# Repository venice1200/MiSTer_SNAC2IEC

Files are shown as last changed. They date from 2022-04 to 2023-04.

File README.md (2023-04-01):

# MiSTer_SNAC2IEC
Inspired from the [SNAC Accessory Converter](https://github.com/blue212/SNAC) and the IEC Support of the C64 Core  
I created together with dtimber this little Adapter PCB for the MiSTer FPGA.  
  
The Adapter converts the MiSTer FPGA User Port (Serial IO) into a Commodore IEC/CBM (Serial) Bus Port.    
Use the Adapter to connect a real Commodore Floppy 1541 or compatible devices (SD2IEC/PI1541) to your MiSTer.  
  
I know there are better and faster ways to load a game into a MiSTer's Core, but this is fun 🚀.  
  
### Compatible & Tested Cores  
C64, C128, Commodore Plus/4  
### Tested Hardware  
[SD2IEC](https://www.c64-wiki.com/wiki/SD2IEC), [PI1541](https://cbm-pi1541.firebaseapp.com/), CBM 1541, CBM1541-II, CBM1571, CBM1581 and Printer MPS-803.
  
Cores and some Hardware Devices are also tested with **JiffyDOS** 🚀.  
  
Double check the User Video below.   
  
### Let's go and have fun...
I used "breakout Parts" for the used Voltage-Levelshifter and the Voltage-Regulator as I had them in stock.  
There is also a Full-SMD-Version available, created by dtimber who created the Case as well.  
  
## PCB's
### First Versions  
### Breakout v1.1/SMD v1.0
The first Picture shows the "Breakout Version", the second the "Full-SMD Version".  
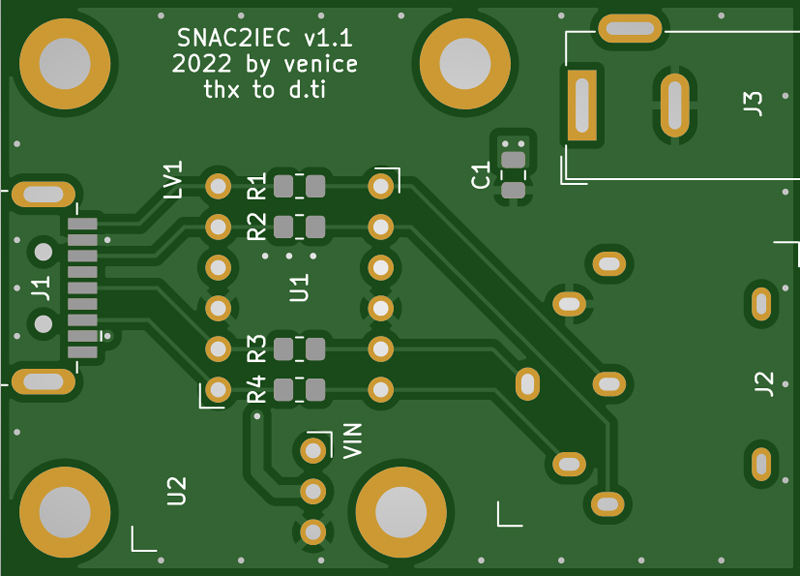
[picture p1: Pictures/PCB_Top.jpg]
 
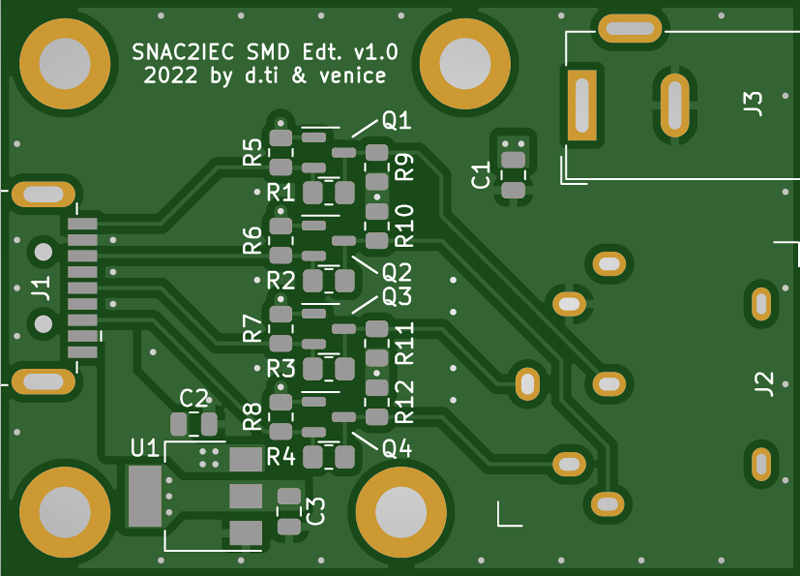
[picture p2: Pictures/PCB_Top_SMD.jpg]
  
  
### Updated Version(s)  
### Breakout v1.2/SMD 1.1  
Changes:
  * Added support for the SRQ Signal which is needed by the C128 Core for **Fast Serial Mode**.  
    The Breakout Version v1.2 need a second Leveshifter **on Top** of the first one to support the SRQ Signal.  
    Solder two small cables from the Pins LV5 and HV5 to one channel of the second Levelshifter.  
  * Removed 5V support (R1-R4) which needs a Standard SNAC Adapter connected before SNAC2IEC.  
  
The first Picture shows the "Breakout Version", the second the "Full-SMD Version".  
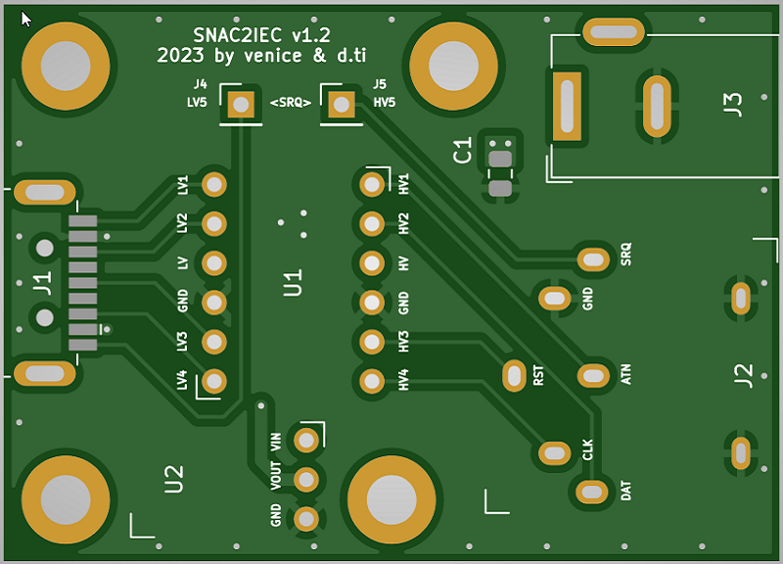
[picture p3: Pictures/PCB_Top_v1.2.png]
 
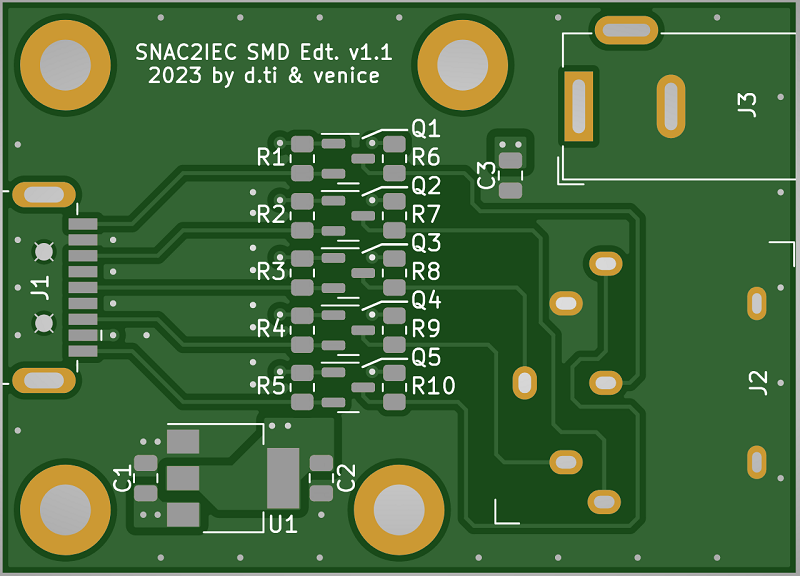
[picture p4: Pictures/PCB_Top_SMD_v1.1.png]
  
  
## More Pictures
The Case was designed to look like the C64 Power Supply  
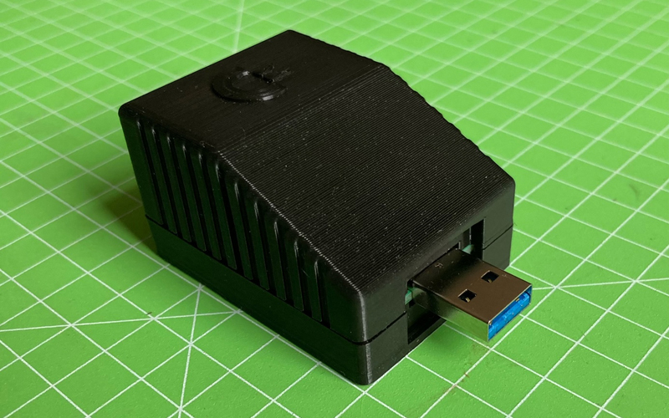
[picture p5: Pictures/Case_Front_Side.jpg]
 
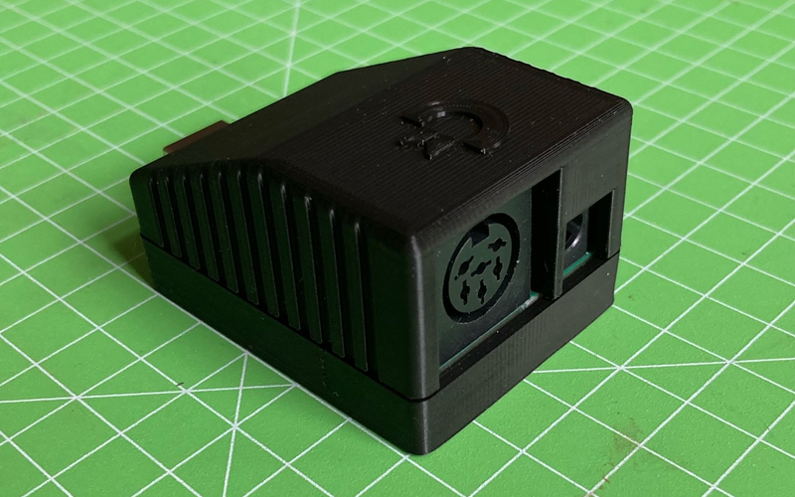
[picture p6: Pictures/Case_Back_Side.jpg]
  
  
Connector View  
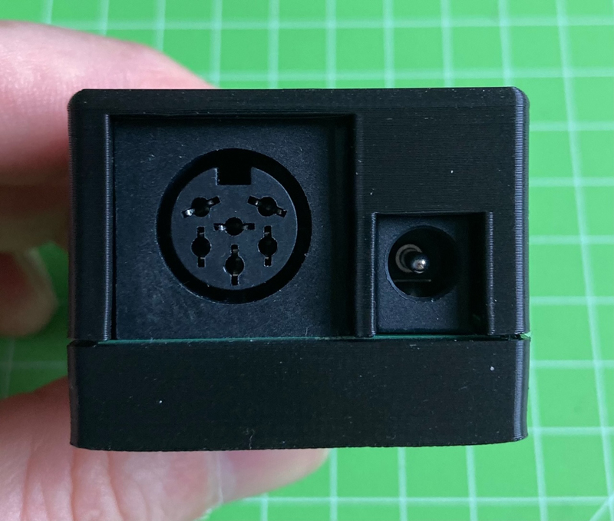
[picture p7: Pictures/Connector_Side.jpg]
  
Left Connector = IEC/CBM Bus, right Connector = 5V Power from SNAC Port  
                                                     
Soldered PCB Version **with** Level Shifter.  
Use it with the Standard IO Board with SNAC Port and **3.3V** Signal Level.  
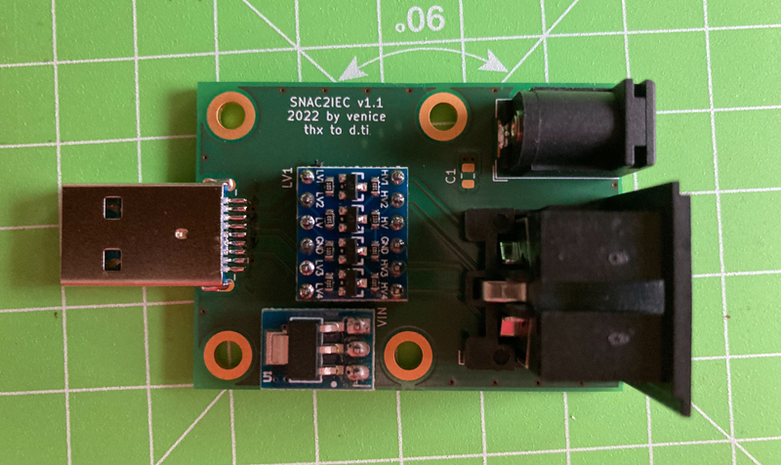
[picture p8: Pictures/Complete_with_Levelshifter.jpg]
  
You need all parts except the "optional's".
  
Soldered PCB Version **without** Level Shifter.  
Only usable with the "first" PCB Versions.  
Use it with SNAC Port's with integrated Level Shifter or with blue212's external SNAC Adapter and **5V** Signal Level.  
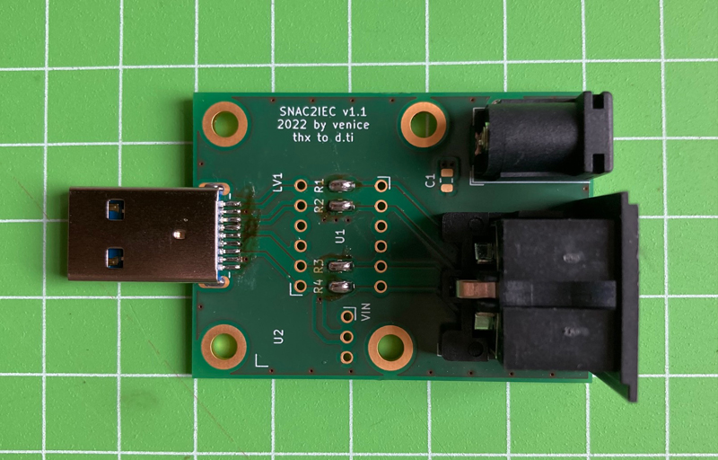
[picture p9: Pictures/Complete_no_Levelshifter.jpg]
  
Just add some 0R 0805 Resistors or a blob of solder to R1,R2,R3 and R4.  

A look inside...  
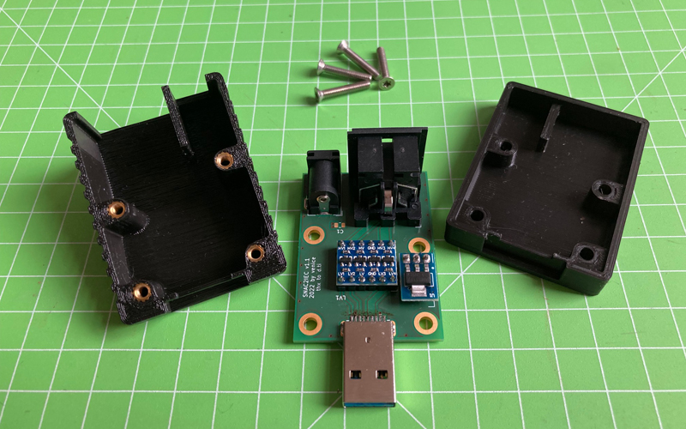
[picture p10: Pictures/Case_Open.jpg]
  
  
All Parts for the Breakout-Version  
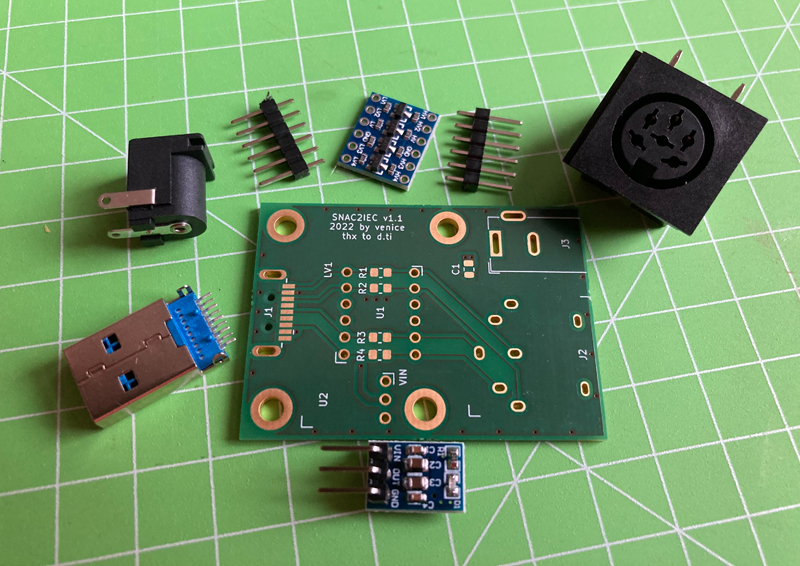
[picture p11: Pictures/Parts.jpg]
  
  
### BOM Breakout Version  
|Part|Type|
|:---|:---|
|R1-R4|0 ohm 0805 resistors (optional, see schematics)|
|C1|4,7uF 0805 capacitor (optional, see schematics)|
|J1|USB3 type A connector|
|J2|6 pin DIN connector (MAS60)|
|J3|DC barrel connector (optional, 5.5/2.1 mm should be fine for most PSUs)|  
|U1|4-Channel Voltage-Levelshifter (5V/3.3V), add a second ***stacked*** Levelshifter for SRQ|
|U2|5V to 3.3V Voltage Regulator|
  
### BOM Full-SMD-Version v1.0 
|Part|Type|
|:---|:---|
|R1-R4|0 ohm 0805 resistors (optional, see schematics)|
|R5-R12|10k 0805 resistors|
|C1-C3|22nf 0805 capacitors|
|Q1-Q4|N-Channel SOT23 MOSFET transistors (BSS138 or similar)|
|U1|3.3v LM1117 SOT223 regulator|
|J1|USB3 type A connector|
|J2|6 pin DIN connector (MAS60)|
|J3|DC barrel connector (optional, 5.5/2.1 mm should be fine for most PSUs)|  
  
### BOM Full-SMD-Version v1.1 
|Part|Type|
|:---|:---|
|R1-R10|10k 0805 resistors|
|C1-C3|22nf 0805 capacitors|
|Q1-Q5|N-Channel SOT23 MOSFET transistors (BSS138 or similar)|
|U1|3.3v LM1117 SOT223 regulator|
|J1|USB3 type A connector|
|J2|6 pin DIN connector (MAS60)|
|J3|DC barrel connector (optional, 5.5/2.1 mm should be fine for most PSUs)|  
  
### Screws and Brass Nuts  
|Part|Type|
|:---|:---|
|Brass Nuts|M3, outer size 4,6mm, lenght 6mm|
|Screws|M3, Counter Sunk, length 17mm|

### Many Thanks to:
*  [dtimber](https://github.com/dtimber) was helping me with KiCad and he is the Creator of the Case and the **SMD-Version**.
  
### Links:  
*  https://github.com/MiSTer-devel/Main_MiSTer/wiki  
*  https://github.com/MiSTer-devel/Main_MiSTer/wiki/User-Port-(Serial-IO)  
*  https://github.com/MiSTer-devel/C64_MiSTer
*  https://github.com/blue212/SNAC
*  https://misterfpga.org/
*  https://misterfpga.org/viewtopic.php?t=4469
  
### User-Videos:  
* https://youtu.be/zR52L662JqI
* https://www.youtube.com/watch?v=zR52L662JqI
* https://www.youtube.com/watch?v=jKdF6Q4ZU_g
* https://www.youtube.com/watch?v=Q-g8Mt_xXnU
* https://www.youtube.com/watch?v=LXGE7Ap88mE
    


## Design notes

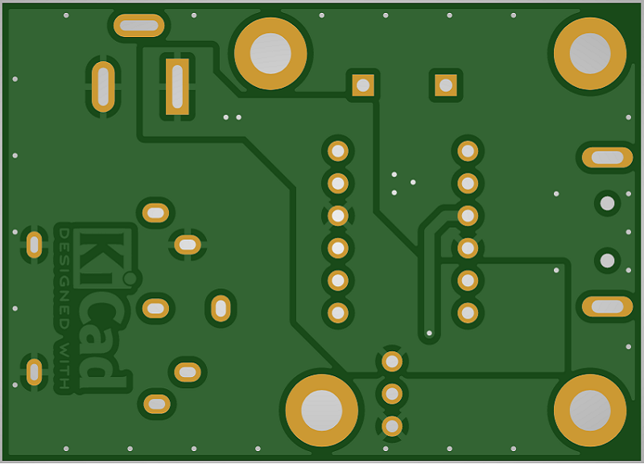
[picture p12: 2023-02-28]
Pictures/PCB_Bottom_v1.2.png

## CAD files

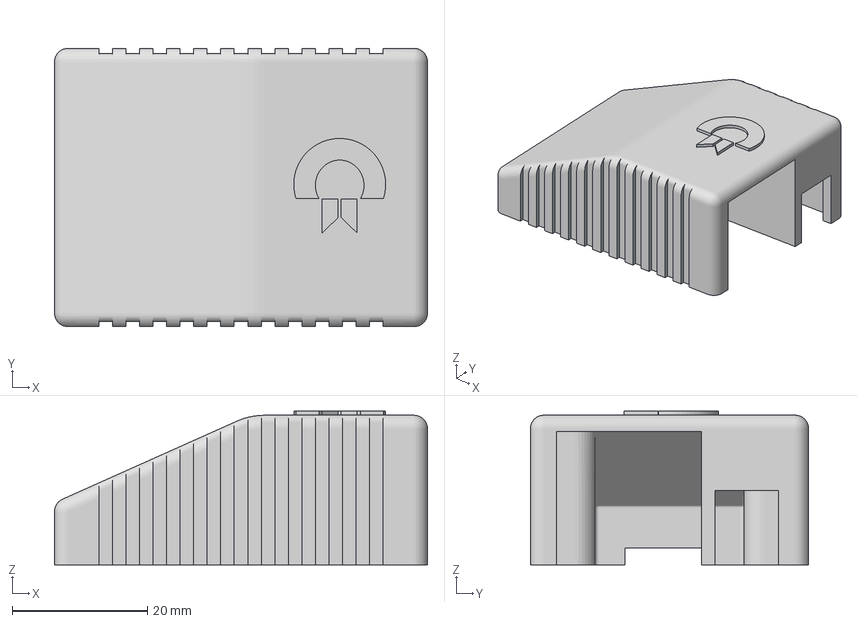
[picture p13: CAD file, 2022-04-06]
3D/Top.3mf
55.2 x 41.2 x 22.8 mm

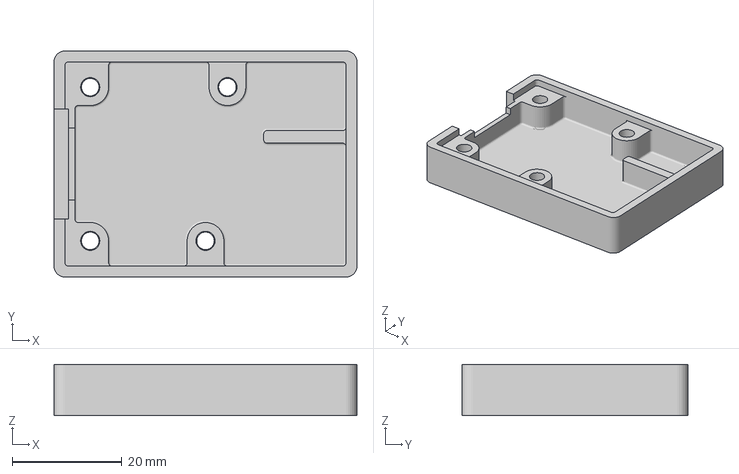
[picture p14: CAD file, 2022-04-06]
3D/Bottom.3mf
55.2 x 41.2 x 9.35 mm

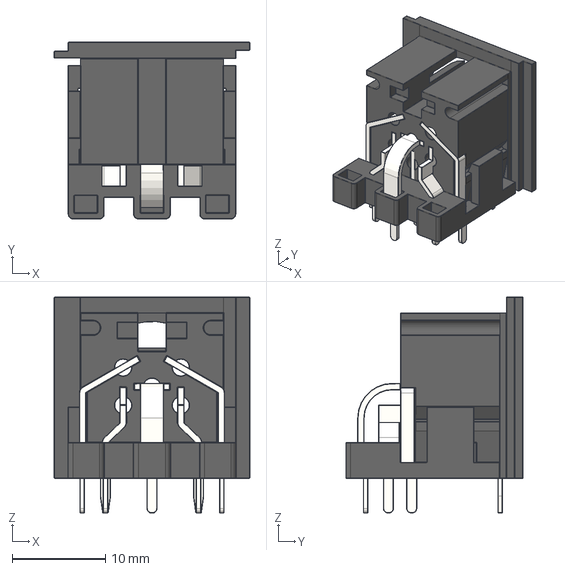
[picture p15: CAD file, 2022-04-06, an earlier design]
KiCad/SD2IEC_SMD_Version/Footprints_und_Symbole/3D/DIN-6-Connector.step
21.0 x 19.0 x 23.2 mm

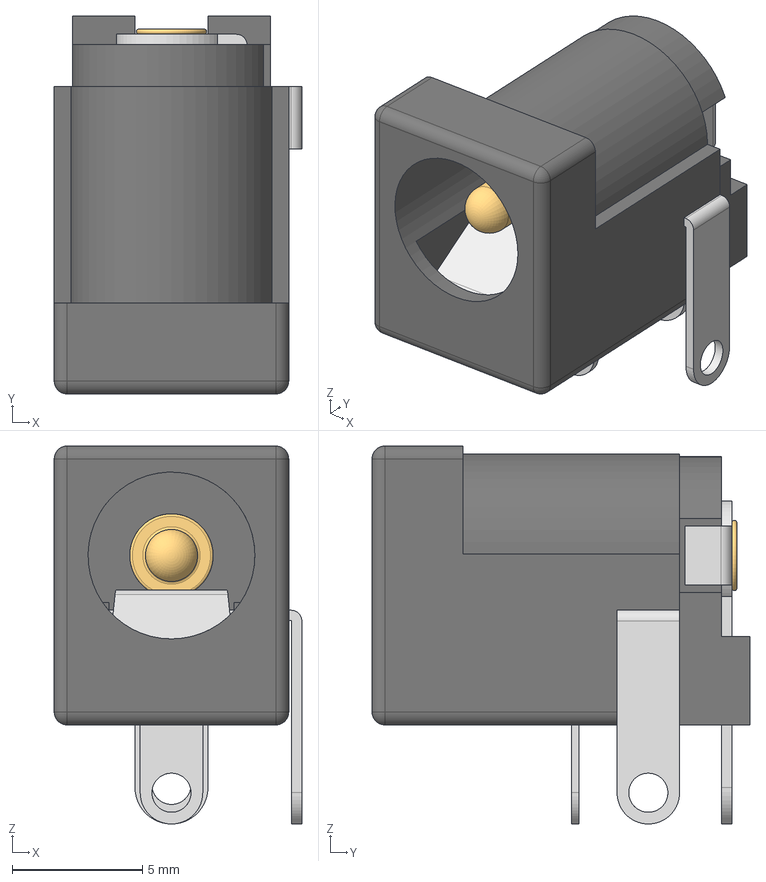
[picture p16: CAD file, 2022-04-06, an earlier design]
KiCad/SD2IEC_SMD_Version/Footprints_und_Symbole/3D/694106301002 (rev1).stp
9.50 x 14.5 x 14.5 mm
6941xx301002
694106301002_PinContact
6941xx301002_Back
6941xx301002_PinContact2
6941xx301002_PinLame
6941xx301002_PinBis

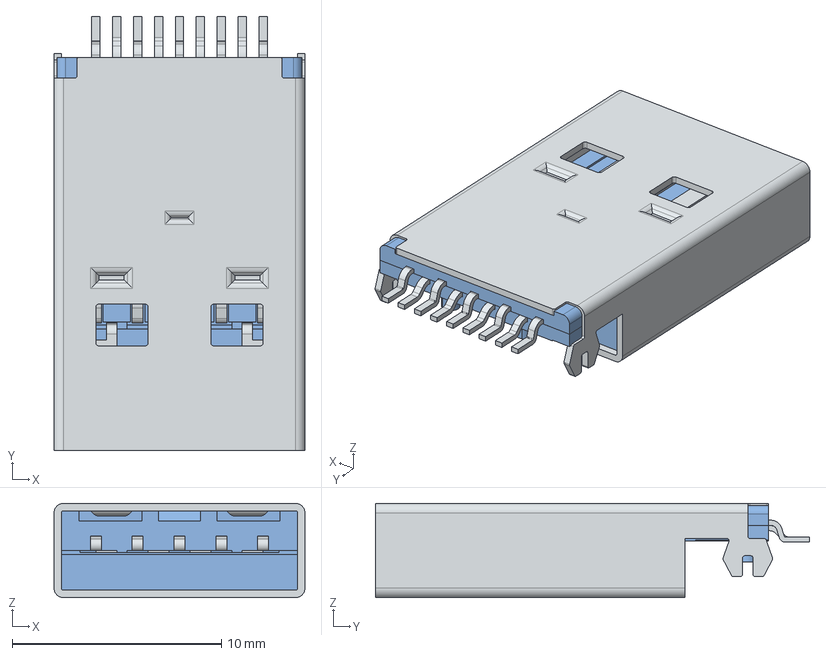
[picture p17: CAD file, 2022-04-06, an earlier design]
KiCad/SD2IEC_SMD_Version/Footprints_und_Symbole/3D/692112030100 (rev1).stp
12.0 x 20.8 x 4.50 mm
692112030100_Housing
692112030100_Shielding
692112030100_Pin2
692112030100_Pin3 x 2
692112030100_Pin1 x 5
692112030100_Housing2
692112030100_Pin5

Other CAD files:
KiCad/SD2IEC_SMD_Version/Footprints_und_Symbole/3D/DIN 45322 Circular Connector.stp
3D/Bottom.stl
3D/SNAC2IEC_Case v8.f3d
3D/Top.stl

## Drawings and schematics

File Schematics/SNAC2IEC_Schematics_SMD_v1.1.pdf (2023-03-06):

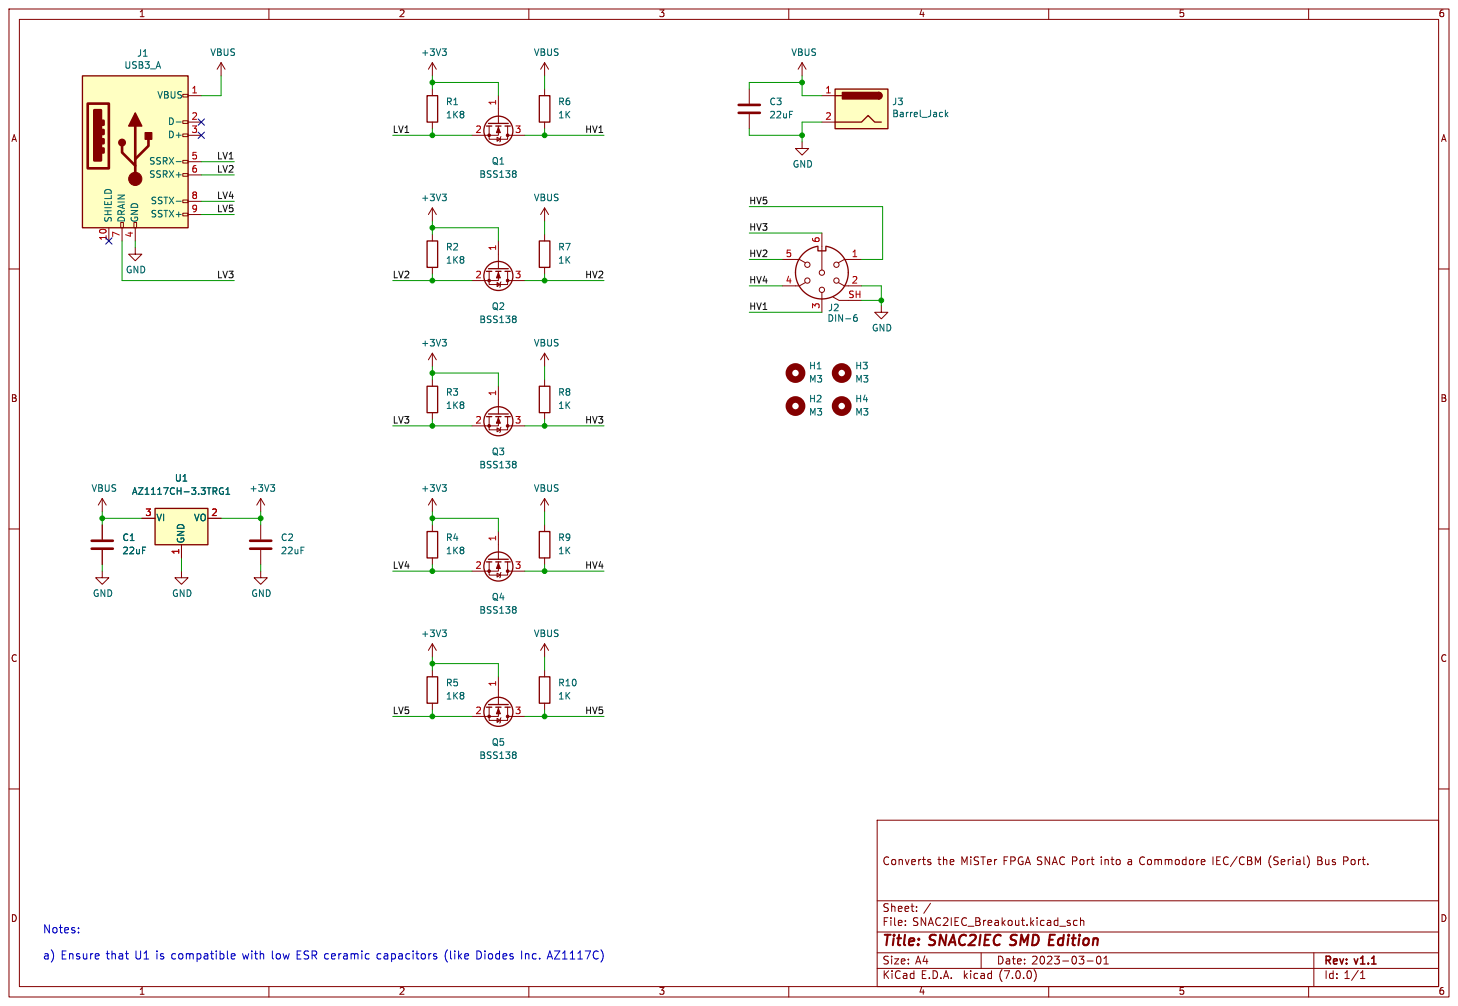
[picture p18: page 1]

Id: 1/1 Title: SNAC2IEC SMD Edition

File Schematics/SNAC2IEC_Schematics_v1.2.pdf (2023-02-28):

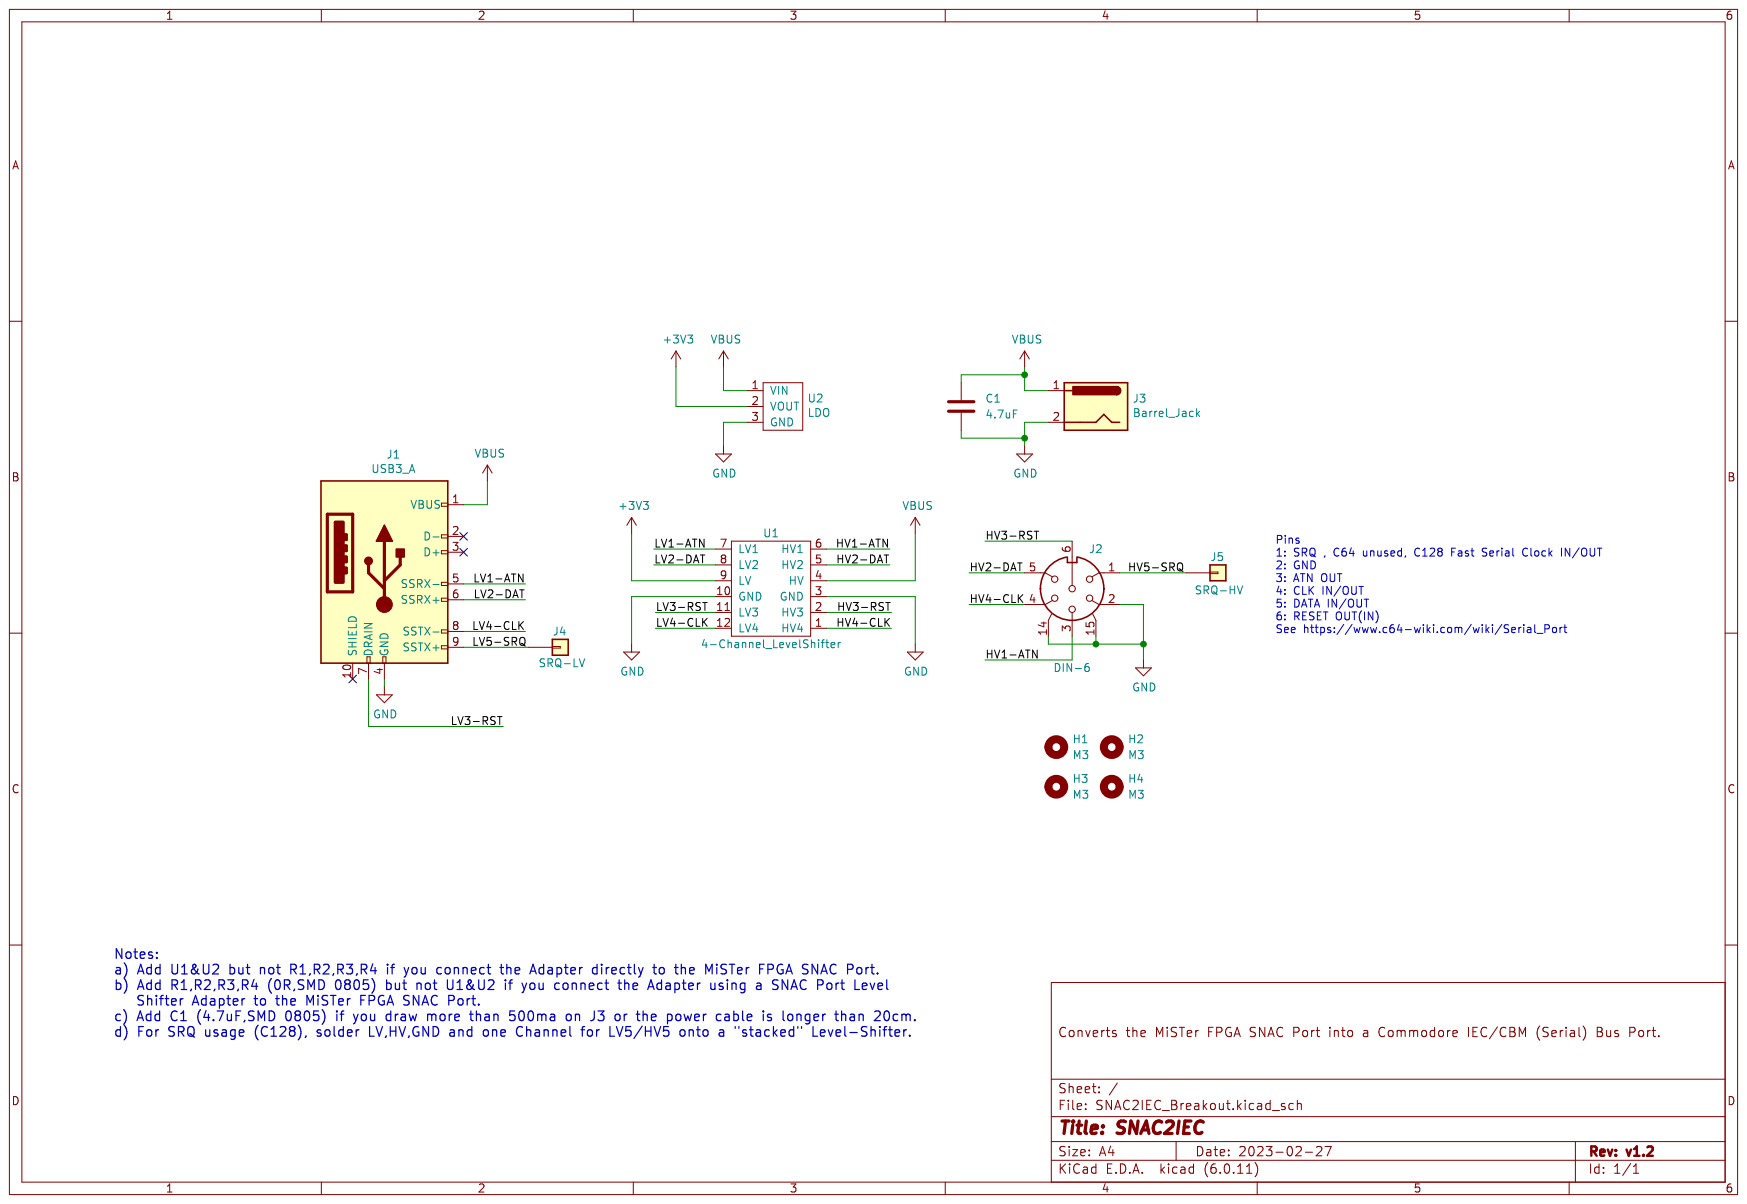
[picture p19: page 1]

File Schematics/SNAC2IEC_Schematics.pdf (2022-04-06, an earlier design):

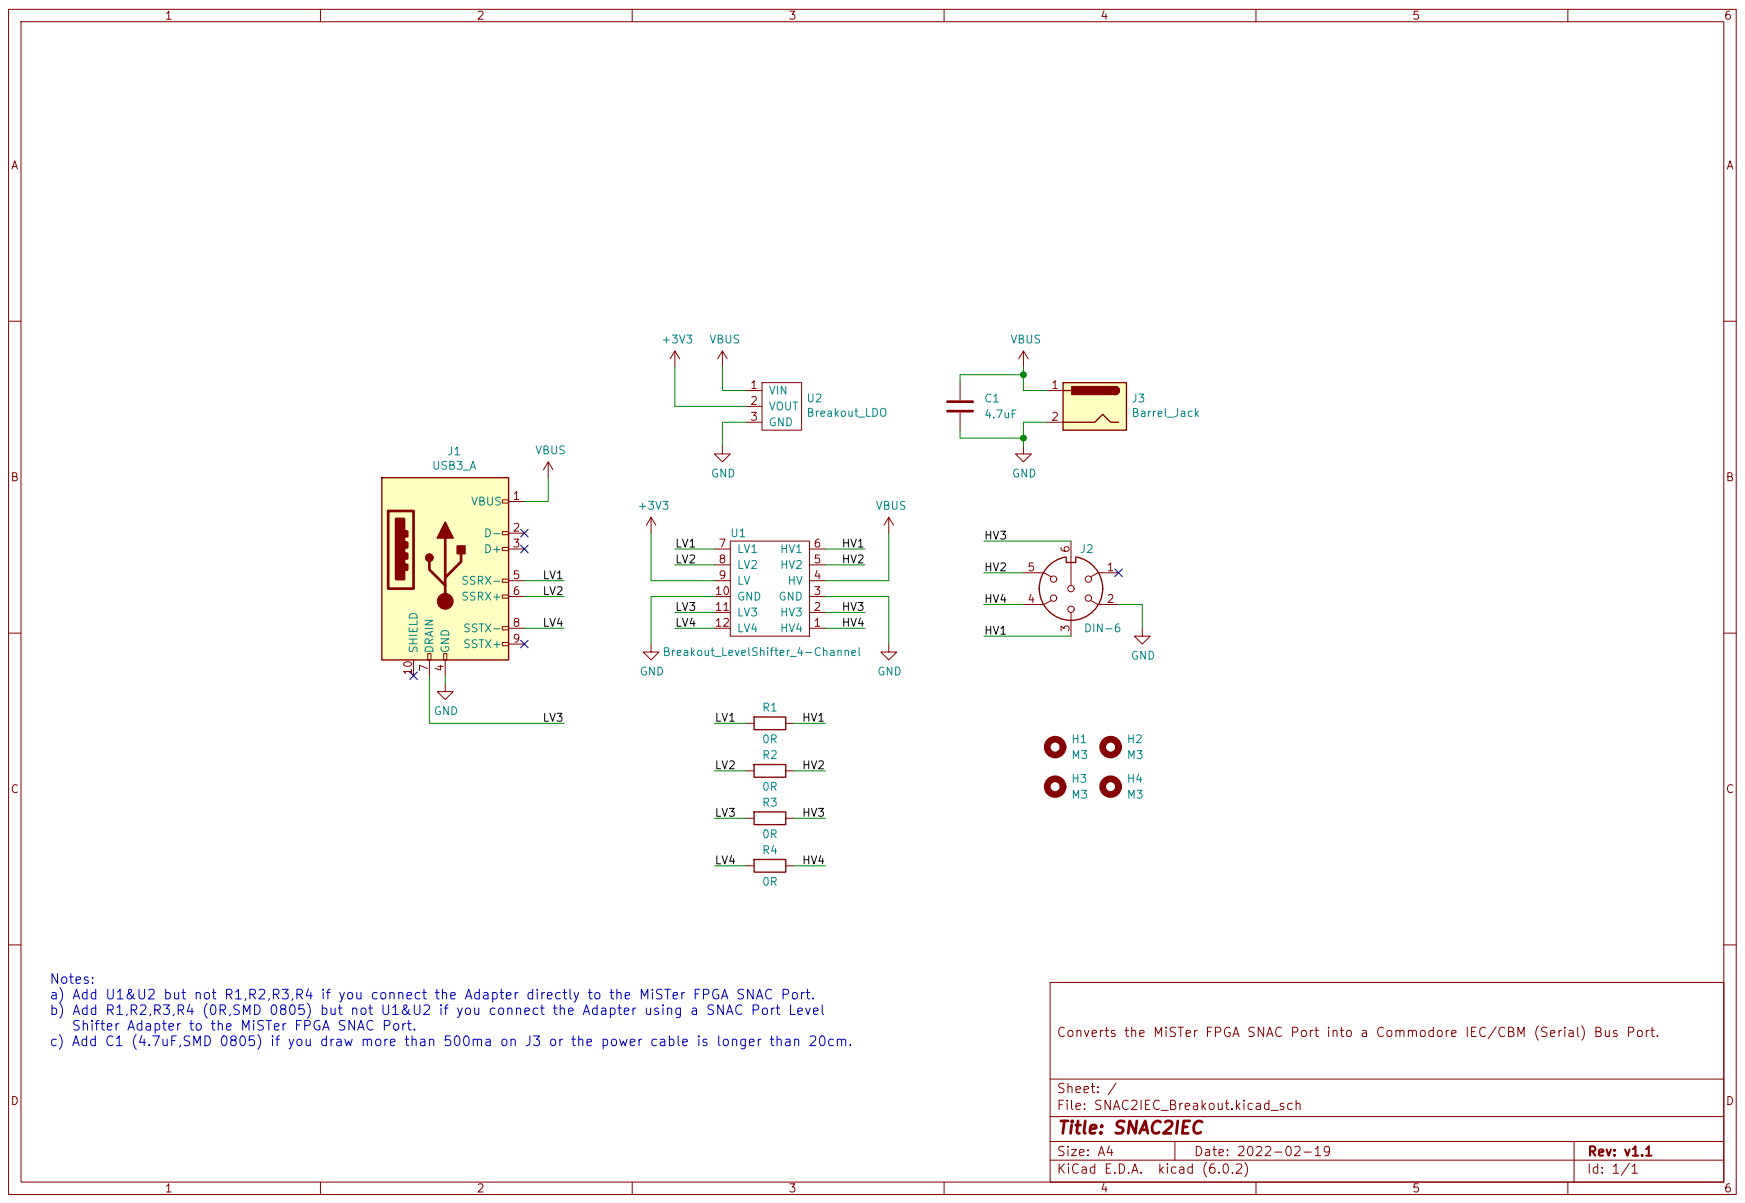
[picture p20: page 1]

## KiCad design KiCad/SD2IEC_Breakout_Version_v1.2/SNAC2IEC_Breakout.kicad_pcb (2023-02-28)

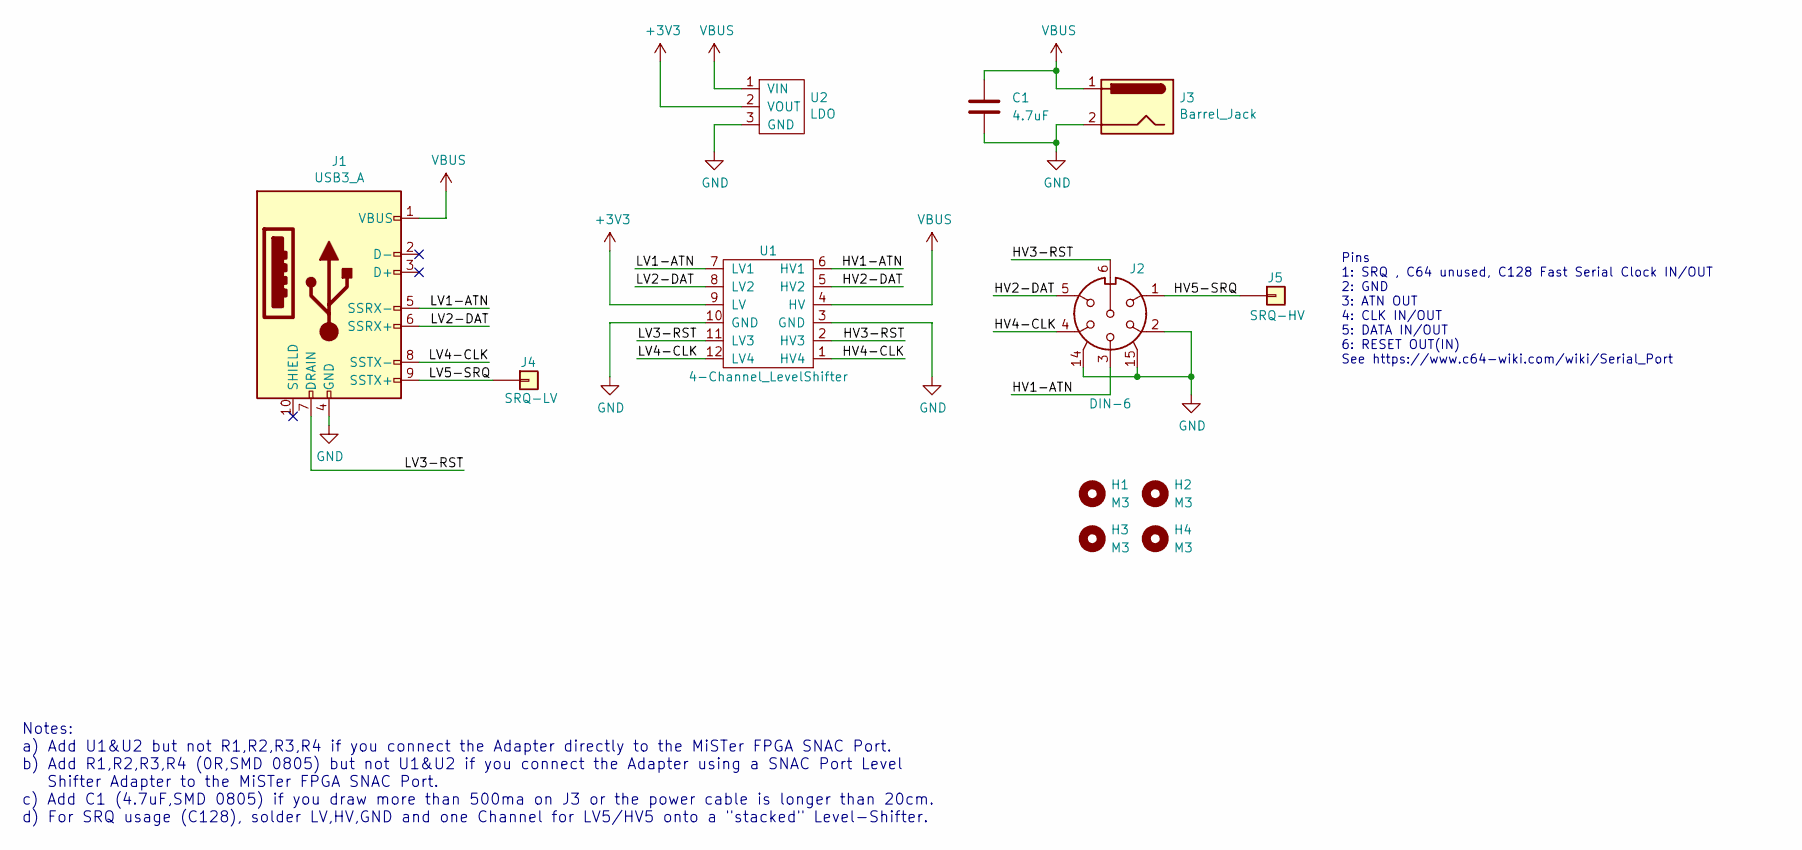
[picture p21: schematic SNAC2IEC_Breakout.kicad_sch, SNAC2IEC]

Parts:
C1: 4.7uF; C_0805_2012Metric
H1, H2, H3, H4: M3; MountingHole_3.2mm_M3_ISO7380_Pad
J1: USB3_A; USB3_A_Plug_Wuerth_692112030100_Horizontal
J2: DIN-6; DIN_6Pin_Print_Connector_IEC_Layout
J3: Barrel_Jack; BarrelJack_Wuerth_6941xx301002
J4: SRQ-LV; PinHeader_1x01_P2.54mm_Vertical
J5: SRQ-HV; PinHeader_1x01_P2.54mm_Vertical
U1: 4-Channel_LevelShifter; Breakout_LevelShiffer_4Channel
U2: LDO; Breakout_LDO_AMS1117_3.3V

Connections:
+3V3: U1.9 (LV), U2.2 (VOUT)
/HV1-ATN: J2.3, U1.6 (HV1)
/HV2-DAT: J2.5, U1.5 (HV2)
/HV3-RST: J2.6, U1.2 (HV3)
/HV4-CLK: J2.4, U1.1 (HV4)
/HV5-SRQ: J2.1, J5.1
/LV1-ATN: J1.5 (SSRX-), U1.7 (LV1)
/LV2-DAT: J1.6 (SSRX+), U1.8 (LV2)
/LV3-RST: J1.7 (DRAIN), U1.11 (LV3)
/LV4-CLK: J1.8 (SSTX-), U1.12 (LV4)
/LV5-SRQ: J1.9 (SSTX+), J4.1
GND: C1.2, J1.4 (GND), J2.2, J2.14, J2.15, J3.2, U1.3 (GND), U1.10 (GND), U2.3 (GND)
VBUS: C1.1, J1.1 (VBUS), J3.1, U1.4 (HV), U2.1 (VIN)

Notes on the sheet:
Notes: a) Add U1&U2 but not R1,R2,R3,R4 if you connect the Adapter directly to the MiSTer FPGA SNAC Port. b) Add R1,R2,R3,R4 (0R,SMD 0805) but not U1&U2 if you connect the Adapter using a SNAC Port Level Shifter Adapter to the MiSTer FPGA SNAC Port. c) Add C1 (4.7uF,SMD 0805) if you draw more than 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
Pins 1: SRQ , C64 unused, C128 Fast Serial Clock IN/OUT 2: GND 3: ATN OUT 4: CLK IN/OUT 5: DATA IN/OUT 6: RESET OUT(IN) See https://www.c64-wiki.com/wiki/Serial_Port

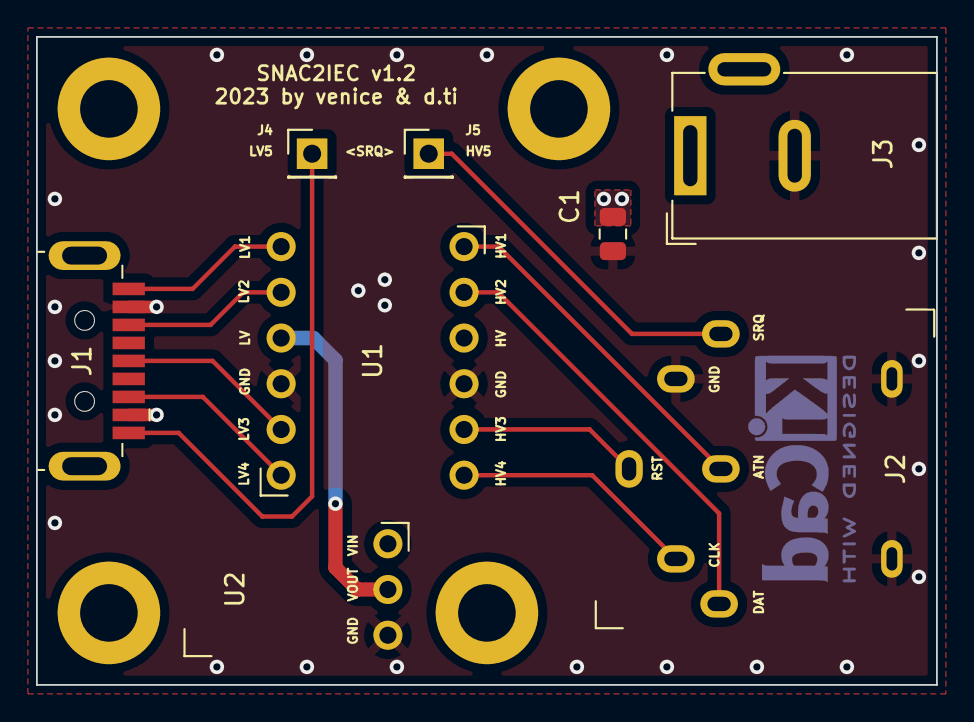
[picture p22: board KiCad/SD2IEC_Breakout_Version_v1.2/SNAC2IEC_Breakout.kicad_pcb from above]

Board: 2 copper layers, 50.0 x 36.0 mm, 12 parts (0 on the bottom side), 13 nets.

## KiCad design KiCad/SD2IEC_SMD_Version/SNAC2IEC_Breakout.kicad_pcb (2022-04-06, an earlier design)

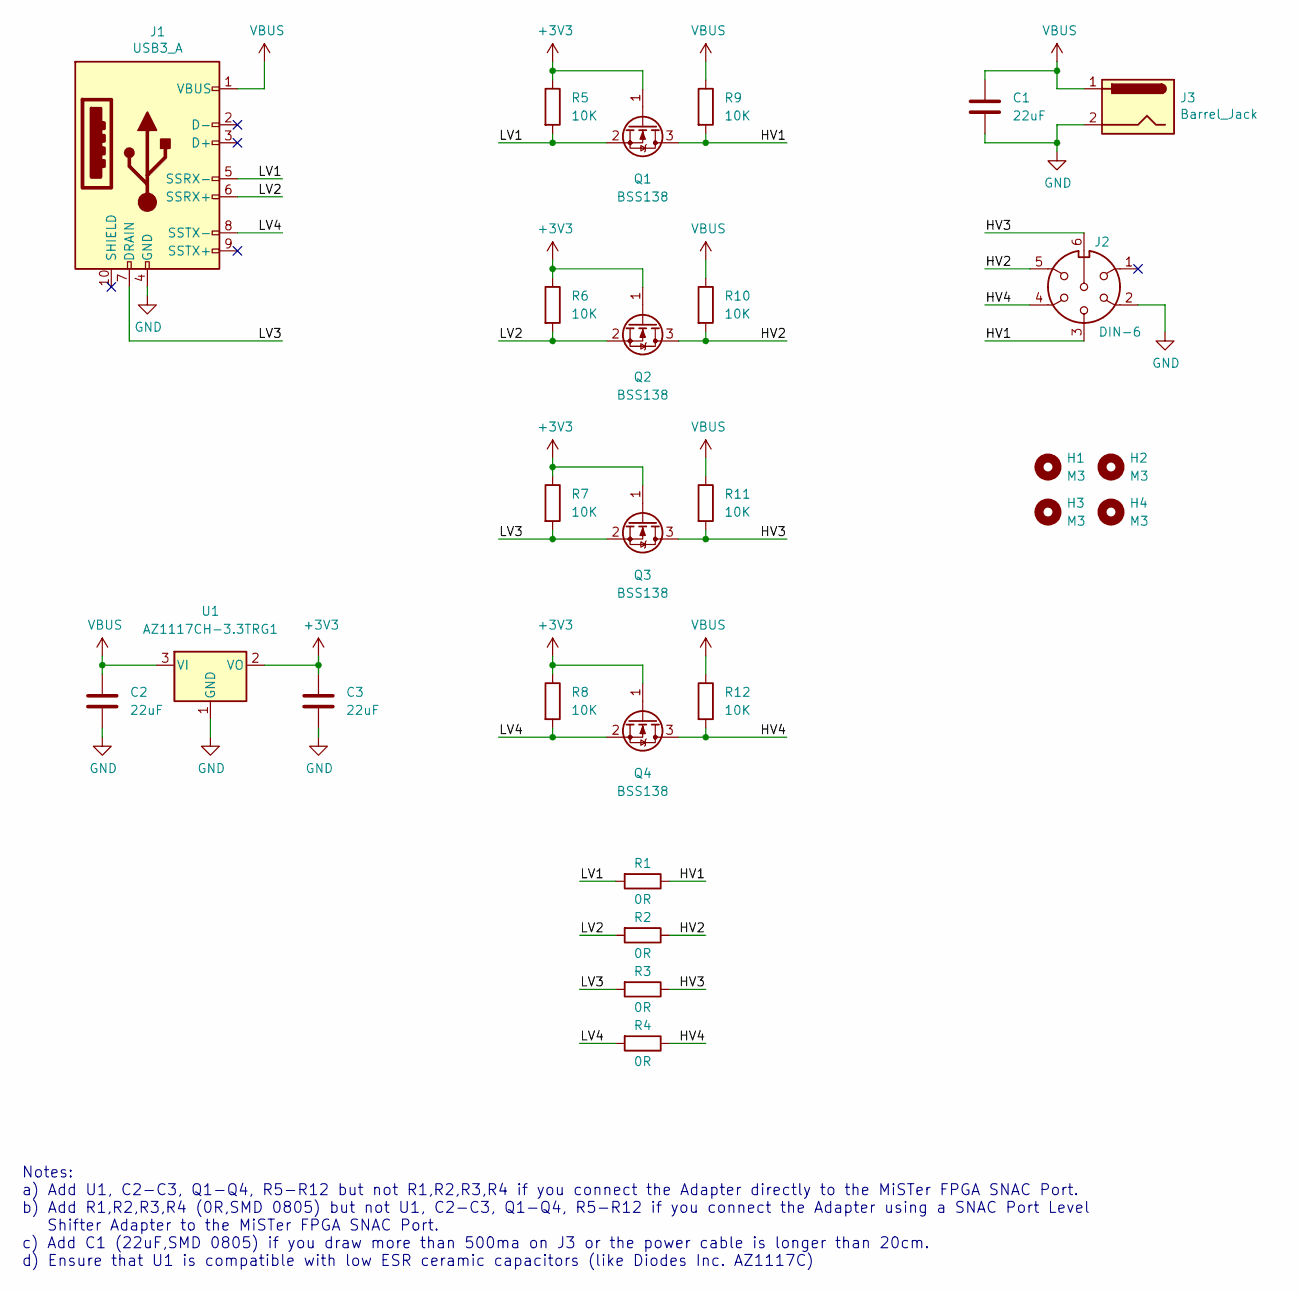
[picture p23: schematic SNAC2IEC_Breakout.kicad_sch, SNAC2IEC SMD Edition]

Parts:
C1, C2, C3: 22uF; C_0805_2012Metric
H1, H2, H3, H4: M3; MountingHole_3.2mm_M3_ISO7380_Pad
J1: USB3_A; USB3_A_Plug_Wuerth_692112030100_Horizontal
J2: DIN-6; DIN_6Pin_Print_Connector_IEC_Layout
J3: Barrel_Jack; BarrelJack_Wuerth_6941xx301002
Q1, Q2, Q3, Q4: BSS138; SOT-23
R1, R2, R3, R4: 0R; R_0805_2012Metric_Pad1.20x1.40mm_HandSolder
R5, R6, R7, R8, R9, R10, R11, R12: 10K; R_0805_2012Metric
U1: AZ1117CH-3.3TRG1; SOT-223-3_TabPin2

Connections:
+3V3: C3.1, Q1.1 (G), Q2.1 (G), Q3.1 (G), Q4.1 (G), R5.1, R6.1, R7.1, R8.1, U1.2 (VO)
/HV1: J2.3, Q1.3 (D), R1.1, R9.2
/HV2: J2.5, Q2.3 (D), R2.1, R10.2
/HV3: J2.6, Q3.3 (D), R3.1, R11.2
/HV4: J2.4, Q4.3 (D), R4.1, R12.2
/LV1: J1.5 (SSRX-), Q1.2 (S), R1.2, R5.2
/LV2: J1.6 (SSRX+), Q2.2 (S), R2.2, R6.2
/LV3: J1.7 (DRAIN), Q3.2 (S), R3.2, R7.2
/LV4: J1.8 (SSTX-), Q4.2 (S), R4.2, R8.2
GND: C1.2, C2.2, C3.2, J1.4 (GND), J2.2, J3.2, U1.1 (GND)
VBUS: C1.1, C2.1, J1.1 (VBUS), J3.1, R9.1, R10.1, R11.1, R12.1, U1.3 (VI)

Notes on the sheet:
Notes: a) Add U1, C2-C3, Q1-Q4, R5-R12 but not R1,R2,R3,R4 if you connect the Adapter directly to the MiSTer FPGA SNAC Port. b) Add R1,R2,R3,R4 (0R,SMD 0805) but not U1, C2-C3, Q1-Q4, R5-R12 if you connect the Adapter using a SNAC Port Level Shifter Adapter to the MiSTer FPGA SNAC Port. c) Add C1 (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

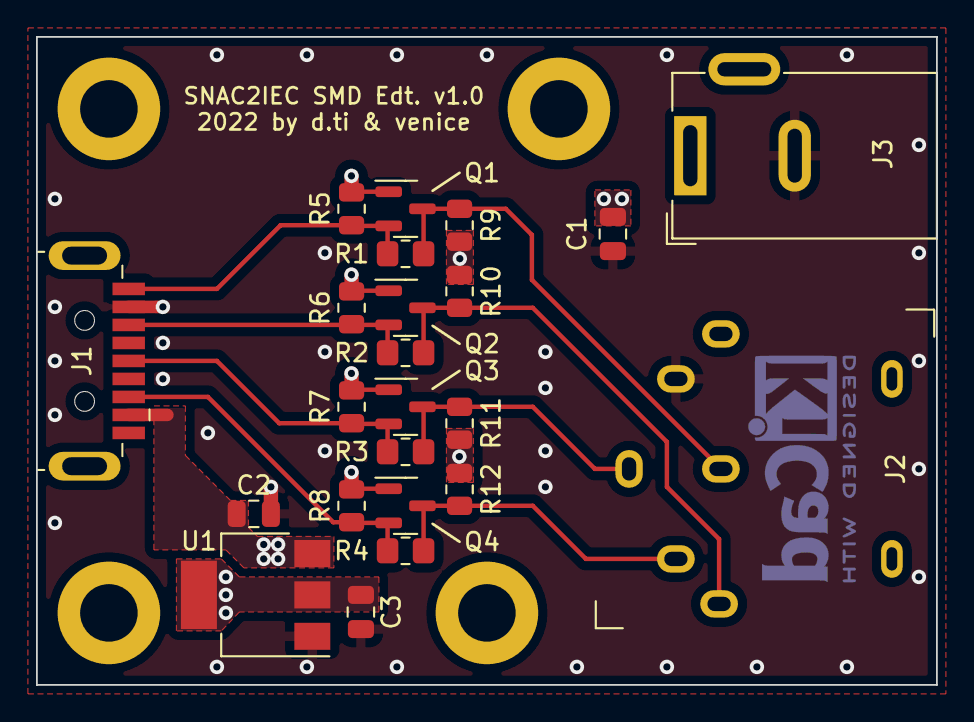
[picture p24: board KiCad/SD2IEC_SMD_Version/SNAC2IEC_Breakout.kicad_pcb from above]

Board: 2 copper layers, 50.0 x 36.0 mm, 27 parts (0 on the bottom side), 11 nets.

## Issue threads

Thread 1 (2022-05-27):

Question about the 3D printed case

NML32, 2022-05-27:
In the photo of the **Case_Open.jpg** What are the size and length of the screws and brass nuts used in the photo.

Thank you for designing and sharing the 3D files.

venice1200, 2022-05-28:
The Screws and Brass Nuts should be M3.
Countersunk Screws with 15mm thread length, overall length about 17mm.
But I think the screws can be a bit shorter.

d.timber confirmed the Brass Nuts are M3, outer size 4.6mm, lenght 6mm.

Closed 2022-05-31.

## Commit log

2022-04-04 Add Case Picture
2022-04-06 Add 3D Files
    [Bottom.3mf, Top.3mf]
2022-04-06 Adding KiCad & Gerber
    [SNAC2IEC_Breakout.kicad_pcb, SNAC2IEC_Breakout.kicad_sch, SNAC2IEC_Breakout.sch]
2022-04-07 New 3D Files
    [Bottom.stl, SNAC2IEC_Case v8.f3d, Top.stl]
2023-02-28 Update Breakout Version to v1.2
    Use a stack of Levelshifter
    [SNAC2IEC_Breakout.kicad_pcb, SNAC2IEC_Breakout.kicad_sch]
2023-04-01 BOM SMD v1.1

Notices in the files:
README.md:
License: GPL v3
